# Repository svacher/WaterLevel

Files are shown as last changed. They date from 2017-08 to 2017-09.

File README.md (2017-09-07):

# WaterLevel
**Gestion du niveau d'eau dans une cuve**  
*Juin 2017*<br>
[]()
[]()

## Besoin
* Mesurer le niveau de remplissage de la cuve du récupérateur d'eau de pluie
* Mesurer la température de l'eau pour éviter le gel (cassure de la cuve et des capteurs)
* Transmettre les données via I2C (soit 4 fils avec l'alimentation)
* Indiquer une alarme température sur une led visible près de la cuve

## Solution
Utilisation d'un ATMEGA328P (utilisé dans le Arduino UNO) de manière autonome (sans interface USB, sans horloge externe).  
RX et TX sont laissés libres en cas d'utilisation ultérieure (debug, wifi, …).  
Un connecteur ISCP est mis en place pour la programmation vu que l'ATMEGA est soudé sur le circuit.

Les informations sont demandées via I2C par un Raspberry Pi qui contrôle l'ensemble de la serre et indique un trop plein de la cuve (envoi SMS ?) ou un risque de gel.

La lecture des capteurs se fait à interval régulier, puis le microcontrôleur utilise le mode Sleep pour économiser l'énergie et augmenter la longévité du matériel.

Les capteurs de niveaux sont immersibles et sans partie électrique en contact avec l'eau (utilisation d'un aimant et d'un interrupteur reed) : https://www.amazon.fr/dp/B01EZGSVZK/ref=pe_3044141_189395771_TE_3p_dp_1.

Le capteur de température est de type analogique mesuré par le µC : AD22100. Autant utiliser un peu plus le µC au lieu d'utiliser des capteurs avec sortie I2C, ils seront plus utiles autre part.  
Des tests comparatifs ont été faits avec un TMP36, mais celui-ci est moins stable, moins précis (10mV/°C pour 22,5mV/°C pour le AD) et la température mesurée semble moins juste.  
Un deuxième capteur de température identique est ajouté sur le circuit, il faut bien utiliser le stock…

## Fonctionnement
La lecture des capteurs est faite toutes les 10 minutes puis le résultat est stocké en RAM.

Pour envoyer les informations, le contrôleur doit recevoir une demande de la part du maître I2C.  
4 commandes sont créés (uniquement en lecture) : lecture de toutes les informations, uniquement le niveau d'eau, uniquement température de l'eau et uniquement température du boîtier.

Commandes I2C :
- 0xFF renvoi toutes les informations à la suite (niveau d'eau, température eau, température boîtier)  
- 0xE0 renvoi le niveau d'eau dans la cuve (1 octet)  
- 0xD0 renvoi la température de l'eau (4 octets)  
- 0xD1 renvoi la température du boîtier (4 octets)  

Une led s'allume dès que la température de l'eau est inférieure à la consigne d'alarme, de manière indépendante, c'est-à-dire sans contrôle du maître I2C.

@bonus : voir plus tard, pour pouvoir modifier la consigne d'alarme de température par commande I2C avec stockage en EEPROM. Gérer aussi une notion de températures minis et maxis en EEPROM.

## Mécanique
Les capteurs de niveaux sont fixés sur une cornière en aluminium (angle avec 1 côté découpé puis plié et percé pour fixer les capteurs), espacés tous les 9cm. Chaque capteur représente 10% du niveau, plus un supplémentaire à environ 3%, qui indique que la cuve est vide.

Le capteur de température y est aussi fixé, le plus bas possible afin d'être toujours dans l'eau. Il sera aussi noyé dans de la colle ou autre pour n'avoir aucune partie électrique dans l'eau (court-circuit, électrolyse). Une 2ème sonde de température est placée avec le circuit.

Toutes les soudures immergées seront protégées par de la gaine thermo-rétractable.

L'idéal est d'insérer le tout dans un tube PVC avec des petits trous en bas afin d'éviter les saletés sur les capteurs. Un poids doit aussi maintenir le tout vertical et au fond de la cuve. Un plot en béton coulé à la base du tube en PVC semble une bonne solution.

Le circuit doit être protégé dans un boitier le plus étanche possible avec une bonne visibilité de l'état de la led.  
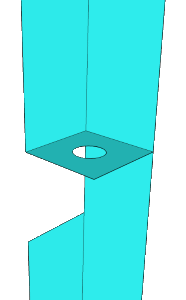
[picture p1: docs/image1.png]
Pliage


## Electronique
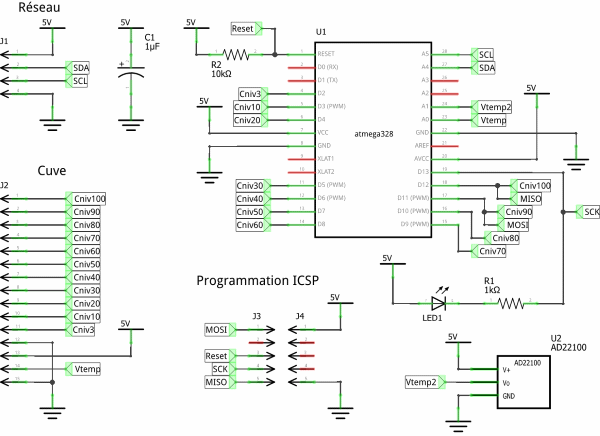
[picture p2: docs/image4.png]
Schéma
  
R2 permet l'utilisation de la programmation ICSP tout en activant le µC en fonctionnement normal.  
La led est branchée en logique inversée pour permettre le bon fonctionnement de SCK (ISCP) et au µC de fournir moins de courant.

Voir [Schéma.fzz](Schéma.fzz) ([Fritzing](http://fritzing.org/download/))

## Programmation
Voir [Programme.ino](Programme.ino) ([Arduino](https://www.arduino.cc/en/Main/Software))

## Coût
Désignation | Montant
-- | --
Atmega328P | 0,00 € (échantillon ATMEL)
Capteurs de niveau d'eau (x11) | 11,10 €
Capteurs de température (x2) | 0,00 € (échantillon Analog Devices)
Led + résistances + condensateur + connecteurs | 1,00 € (+ stock)
Cornière en alu + Tube PVC + plot de béton | 7,05 €
Total | 19,15 €

## Réalisation
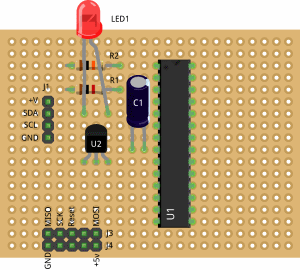
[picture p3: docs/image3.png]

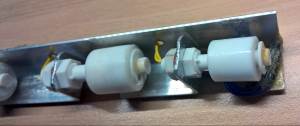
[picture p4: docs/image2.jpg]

Réalisation
Réalisation

## Conclusion
I2C limite la longueur du câble à 50 cm...

## Mémo
ID du système en I2C : **0x20**  
Consigne d'alarme : **2°C**  
En cas de gel, le mieux est de vider la cuve, sinon d'enlever les capteurs.

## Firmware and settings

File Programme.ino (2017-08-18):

/**
 * Cuve
 * 
 * gestion du niveau et de la température de la cuve d'eau (récupérateur)
 * 
 * @date  Juillet 2017
 * @see   https://docs.google.com/document/d/1D_nuetByEitFJuT3LoqX1b15HQhd-w6IJazHjmXhHUk/
 */

/**
 * Librairies
 */
#include <avr/sleep.h>
#include <avr/power.h>
#include <avr/interrupt.h>
#include <Wire.h>

/**
 * Constantes
 */
#define I2C_ADRESS 0x20   // Adresse I2C du module
#define TEMP_ALARM 2.00F  // Alarme de température
#define Cniv3 2           // Niveau 3%
#define Cniv10 3          // Niveau 10%
#define Cniv20 4          // Niveau 20%
#define Cniv30 5          // Niveau 30%
#define Cniv40 6          // Niveau 40%
#define Cniv50 7          // Niveau 50%
#define Cniv60 8          // Niveau 60%
#define Cniv70 9          // Niveau 70%
#define Cniv80 10         // Niveau 80%
#define Cniv90 11         // Niveau 90%
#define Cniv100 12        // Niveau 100%
#define Vtemp A0          // Sonde de température de l'eau
#define Vtemp2 A1         // Sonde de température du circuit
#define Alarm 13          // LED d'alarme de température

/**
 * Variables
 */
byte levelWater;          // Niveau d'eau dans la cuve
float tempWater;          // Température de l'eau
float tempCircuit;        // Température du circuit
byte i2cCommand;          // Commande I2C reçue

/**
 * Initialisation
 */
void setup() {
  
  // Entrées
  pinMode(Cniv3, INPUT_PULLUP);
  pinMode(Cniv10, INPUT_PULLUP);
  pinMode(Cniv20, INPUT_PULLUP);
  pinMode(Cniv30, INPUT_PULLUP);
  pinMode(Cniv40, INPUT_PULLUP);
  pinMode(Cniv50, INPUT_PULLUP);
  pinMode(Cniv60, INPUT_PULLUP);
  pinMode(Cniv70, INPUT_PULLUP);
  pinMode(Cniv80, INPUT_PULLUP);
  pinMode(Cniv90, INPUT_PULLUP);
  pinMode(Cniv100, INPUT_PULLUP);
  
  // Sorties
  pinMode(Alarm, OUTPUT);

  // I2C
  Wire.begin(I2C_ADRESS);
  Wire.onReceive(i2cReceive);
  Wire.onRequest(i2cRequest);
  i2cCommand = 0;
}

/**
 * Programme principal
 */
void loop() {
  
  readWaterLevel();
  readTemperatures();
  setAlarme();
  setSleep();
}

/**
 * Indique le niveau d'eau dans la variable levelWater
 */
void readWaterLevel() {
  
  if (!digitalRead(Cniv100)) levelWater = 100;
  else if (!digitalRead(Cniv90)) levelWater = 90;
  else if (!digitalRead(Cniv80)) levelWater = 80;
  else if (!digitalRead(Cniv70)) levelWater = 70;
  else if (!digitalRead(Cniv60)) levelWater = 60;
  else if (!digitalRead(Cniv50)) levelWater = 50;
  else if (!digitalRead(Cniv40)) levelWater = 40;
  else if (!digitalRead(Cniv30)) levelWater = 30;
  else if (!digitalRead(Cniv20)) levelWater = 20;
  else if (!digitalRead(Cniv10)) levelWater = 10;
  else if (!digitalRead(Cniv3)) levelWater = 3;
  else levelWater = 0;
}

/**
 * Indique la température de l'eau dans la variable tempWater
 * et celle du circuit dans tempCircuit
 */
void readTemperatures() {
  
  int value = analogRead(Vtemp);
  tempWater = ((value * 5.0 / 1024) - 1.375) * (1000 / 22.5);
  value = analogRead(Vtemp2);
  tempCircuit = ((value * 5.0 / 1024) - 1.375) * (1000 / 22.5);
}

/**
 * Allume la led si la température de l'eau est inférieure ou égale à la consigne
 * Attention : la led est branchée en logique inversée
 */
void setAlarme() {
  
  if (tempCircuit <= TEMP_ALARM)
    digitalWrite(Alarm, LOW);
  else
    digitalWrite(Alarm, HIGH);
}

/**
 * Met en sommeil le processeur
 */
void setSleep() {
  
  // TODO
}

/**
 * Reçoit des données I2C (Ecriture)
 * 
 * Commandes :
 * - 0xFF renvoi toutes les informations à la suite (niveau d'eau, température eau, température boîtier)
 * - 0xE0 renvoi le niveau d'eau dans la cuve (1 octet)
 * - 0xD0 renvoi la température de l'eau (4 octets)
 * - 0xD1 renvoi la température du boîtier (4 octets)
 */
void i2cReceive(int datasLength) {
  
  i2cCommand = Wire.read();
}

/**
 * Envoi des données I2C suite à une demande (Lecture)
 */
void i2cRequest() {

  if (i2cCommand == 0xFF) { // Toutes les données
    Wire.write(levelWater);
    Wire_SendDouble(tempWater);
    Wire_SendDouble(tempCircuit);
  }
  else if (i2cCommand == 0xE0) // Niveau d'eau
    Wire.write(levelWater);
  else if (i2cCommand == 0xD0) // Température de l'eau
    Wire_SendDouble(tempWater);
  else if (i2cCommand == 0xD1) // Température du boîtier
    Wire_SendDouble(tempCircuit);
  else  // Commande inconnue
    Wire.write(0xFF);
    
}

/**
 * Envoi un double par la liaison I2C
 */
void Wire_SendDouble(float f){
  
    union Sharedblock
    {
        byte octet[4];
        float data;
    } datas;
    datas.data = f;
    Wire.write(datas.octet, 4);
}
 

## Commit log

2017-08-18 Add files via upload
    Schéma au format fritzing
    [Schéma.fzz]
2017-08-18 Ajout du programme Arduino
2017-09-05 Ajout des photos
2017-09-05 Ajout des photos de la réalisation
2017-09-05 Ajustement de la taille des images
